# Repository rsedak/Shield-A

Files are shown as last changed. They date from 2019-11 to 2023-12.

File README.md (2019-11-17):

Introduction
============

Shield-A is Arduino Uno based shield for student education compatible with BASCOM-AVR(C) and Arduino IDE.
During programming please keep in mind next design rules:
- D0-D7 — LEDs can be used only if D12 is set to OUTPUT HIGH state
- LCD 1602 — can be used only if A3 is set to OUTPUT HIGH state
- RGB LED — are connected in matrix (D5-D7 - colors; D8-D11 - LEDs)
- D12 — enables D0-D7 LEDs
- D13 — reserved for buzzer
- A0 — reserved for potentiometer
- A1,A2 — reserved for switch in INPUT_PULLUP mode
- A3 — enables LCD 1602 back-light
- A4,A5 — reserved for I2C communication with on board pull-up resistors

Contributors
------------
- Petar Jurković — an initial idea for the educational shield with a list of features, QA test.
- Vladimir Mitrović — features, BASCOM-AVR expertise, schematic design
- Robert Sedak — features, Arduino expertise, schematic design, CAD design. 

Application
-----------
Robert Sedak made a video with examples programmed in Arduino IDE:

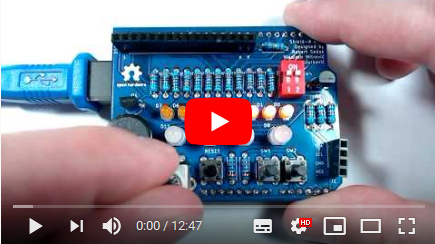
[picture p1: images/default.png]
Shield application (https://youtu.be/6tAJYVBwVqs "Shield-A examples")


You can download examples from [here](examples/). 
Examples which name ends with '_R' are solution with register maniputalion.

Bill Of Materials
-----------------
- 1 ea., PCB from [PCBway.com](https://www.pcbway.com/project/shareproject/Shield_A_for_Arduino_Uno.html)
- 9 ea., 1K ohm 1/4W 1% Resistor (R1-R8, R13)
- 2 ea., 100 ohm 1/4W 1% Resistor (R9, R10)
- 2 ea., 560 ohm 1/4W 1% Resistor (R11-R12)
- 4 ea., 10K ohm 1/4W 1% Resistor (R14, R15, R17, R18)
- 2 ea., 18.2 ohm 1/4W 1% Resistor (R16)
- 8 ea., LED 3mm (D0-D7)
- 4 ea., RGB LED 5mm common Katode (D8-D11)
- 1 ea., 14x7.5mm passive electronic piezoelectric buzzer SE
- 2 ea., MOSFET BS170
- 1 ea., 3386-P 10K potentiometer with knob
- 1 ea., RV09 10K potentiometer - long shaft
- 1 ea., 2.54mm pitch slide DIP switch 2-bit
- 1 ea., 6x6x4.3mm SPST Momentary push switch
- 2 ea., 6x6x10mm SPST Momentary push switch
- 1 ea., 1x16Pin 2.54mm Straight Pin Header - Black
- 1 ea., 1x10Pin 2.54mm Straight Pin Header - Black
- 2 ea., 1x8Pin 2.54mm Straight Pin Header - Black
- 1 ea., 1x6Pin 2.54mm Straight Pin Header - Black
- 1 ea., 1x4 pin 2.54mm Socket Connector
- 1 ea., 1x16 pin 2.54mm Socket Connector
- 1 ea., LCD 1602 HD44780 (pin 15 is anode, pin 16 is katode)

Design Files
------------
This project is designed using Open Source [KiCad](http://kicad-pcb.org/). Design files are located in the [design_files](design_files/) folder.  You can see the [schematic](images/shield-a_schematic.png).

Gerber files
------------
You can download gerber files from [here](gerber/shield_a_v1.1.zip).

Firmware
--------
This project can be programmed using the Open Source [Arduino](https://www.arduino.cc/) and [BASCOM-AVR(C)](https://www.mcselec.com/index.php?option=com_content&task=view&id=14&Itemid=103).
Arduino examples are located in [examples](examples/) folder.

Assembly Instructions
---------------------
TBD

License
-------
[Attribution-ShareAlike 4.0 International (CC BY-SA 4.0)](https://creativecommons.org/licenses/by-sa/4.0/)

You are free to:
- Share — copy and redistribute the material in any medium or format
- Adapt — remix, transform, and build upon the material

This license is acceptable for Free Cultural Works.
- The licensor cannot revoke these freedoms as long as you follow the license terms.

Under the following terms:
- Attribution — You must give appropriate credit, provide a link to the license, and indicate if changes were made. You may do so in any reasonable manner, but not in any way that suggests the licensor endorses you or your use.
- ShareAlike — If you remix, transform, or build upon the material, you must distribute your contributions under the same license as the original.

No additional restrictions — You may not apply legal terms or technological measures that legally restrict others from doing anything the license permits.

Reference Designs ARE PROVIDED "AS IS" AND "WITH ALL FAULTS". Authors DISCLAIMS ALL OTHER WARRANTIES, EXPRESS OR IMPLIED, REGARDING PRODUCTS, INCLUDING BUT NOT LIMITED TO, ANY IMPLIED WARRANTIES OF MERCHANTABILITY OR FITNESS FOR A PARTICULAR PURPOSE.
Authors may make changes to specifications and product descriptions at any time, without notice. The Customer must notrely on the absence or characteristics of any features or instructions marked "reserved" or "undefined." 
Authors reservesthese for future definition and shall have no responsibility whatsoever for conflicts or incompatibilities arising from future changes to them. The product information on the Web Site or Materials is subject to change without notice. Do not finalize a design with this info.

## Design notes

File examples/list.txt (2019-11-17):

Examples
001 D0 blinks
002 D0 and D1 blinks
003 D0-D7 turning on LEDs - from D0 to D7
004 D0-D7 turning on LEDs - from D0 to D7; turning off LEDs - from D7 to D0
005 D0-D7 running light - from from D0 to D7
006 D0-D7 running light - from D0 to D7 and from D7 to D0
007 D0-D7 turning on LEDs - from D7 to D0
008 D0-D7 turning on LEDs - from D7 to D0; turning off LEDs - from D0 to D7
009 D0-D7 running light - from D7 to D0
010 D0-D7 running light - from D7 to D0 and from D0 to D7
011 D0-D7 four LEDs shift from D7 to D0
012 D0-D7 four LEDs shift from D0 to D7
013 D0-D7 two even LEDs shift from D7 to D0
014 D0-D7 two even LEDs shift from D0 to D7
015 D0-D7 animation
016 RGB matrix - red
017 RGB matrix - red, blue, green - one RGB LED
018 RGB matrix - red, blue, green - four RGB LED
019 RGB matrix - white - one RGB
020 RGB matrix - multiplexing four RGB LED
021 RGB matrix - multiplexing four RGB LED
022 RGB matrix - multiplexing four RGB LED
023 RGB matrix - multiplexing four RGB LED
024 RGB matrix - multiplexing four RGB LED
025 Buzzer and SW1
026 Buzzer, SW1 and SW2 - different tone
027 D0-D7, SW1, SW2 - Turning On / Off D0
028 D0-D7, SW1, SW2 - while SW1 is pressed, light runs in direction from D0 to D7; while SW2 is pressed, light runs in direction from D7 to D0
029 D0-D7, SW1, SW2 - for SW1 pressed, light moves in direction from D0 to D7 for one LED; for SW2 pressed, light moves in direction from D7 to D0 for one LED
030 D0-D7, SW1, SW2 - for SW1 pressed, light moves in direction from D0 to D7 for one LED; for SW2 pressed, light moves in direction from D7 to D0 for one LED - debounce
031 D0-D7, SW1, SW2 - when SW1 is short pressed, light moves in direction from D0 to D7 for one LED; when SW1 is pressed for 3 seconds, light moves in direction from D0 to D7 for one LED continuously; when SW2 is short pressed, light moves in direction from D7 to D0 for one LED; when SW2 is pressed for 3 seconds, light moves in direction from D7 to D0 for one LED continuously  - debounce
032 D0-D7 and RV1 - running light - from D0 to D7 depending on potentiometer shaft position
033 D0-D7 and RV1 - running light - from D7 to D0 depending on potentiometer shaft position
034 D0-D7 and RV1 - turning on LEDs - from D0 to D7 depending on potentiometer shaft position
035 D0-D7 and RV1 - turning on LEDs - from D7 to D0 depending on potentiometer shaft position
036 D0-D7 and RV1 - turning on LEDs from the centre to the edge depending on potentiometer shaft position
037 D0-D7 and RV1 - turning on LEDs from the edge to the centre depending on potentiometer shaft position
038 RV1 and buzzer - Making a noise
039 RV1, LCD - Show analogue input value
040 RV1, LCD (I2C) - Show analogue input value

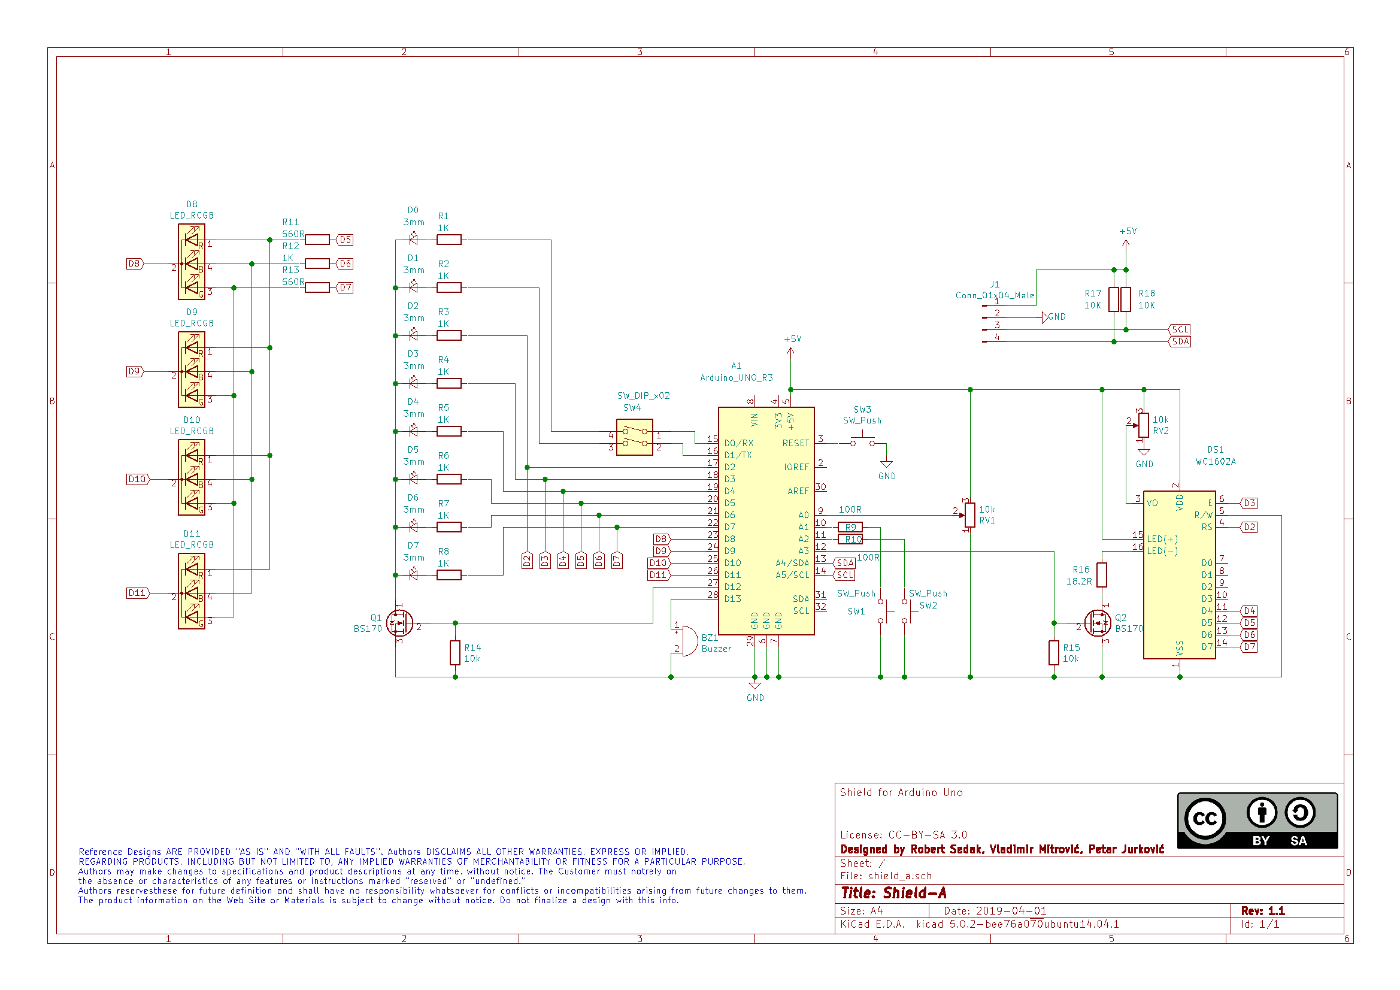
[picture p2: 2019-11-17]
images/shield-a_schematic.png

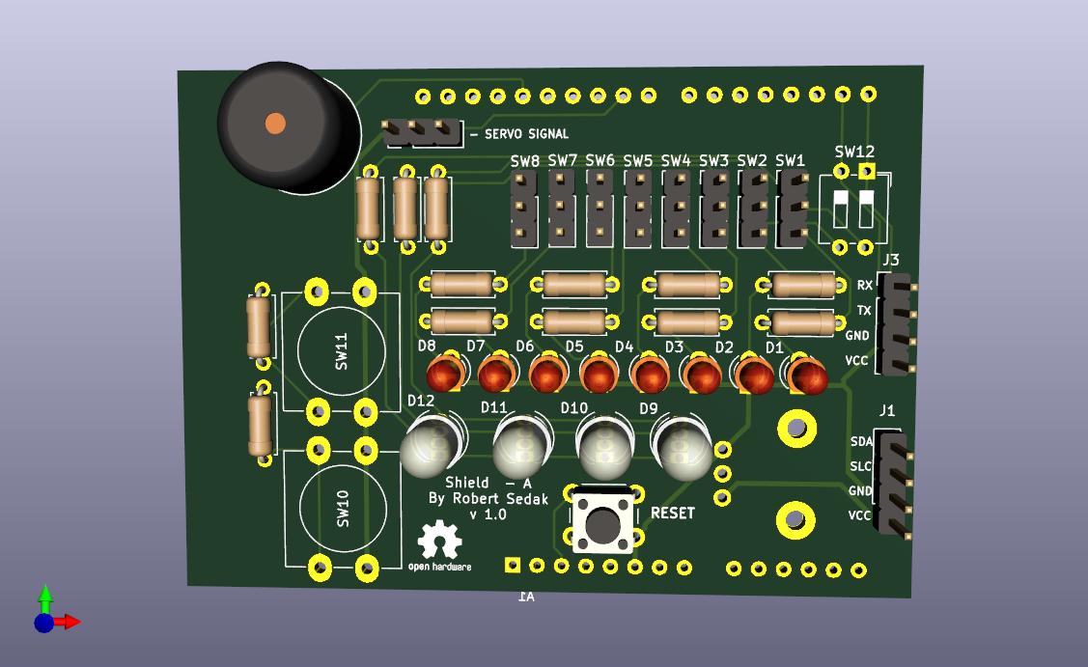
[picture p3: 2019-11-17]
images/shield-a.jpg

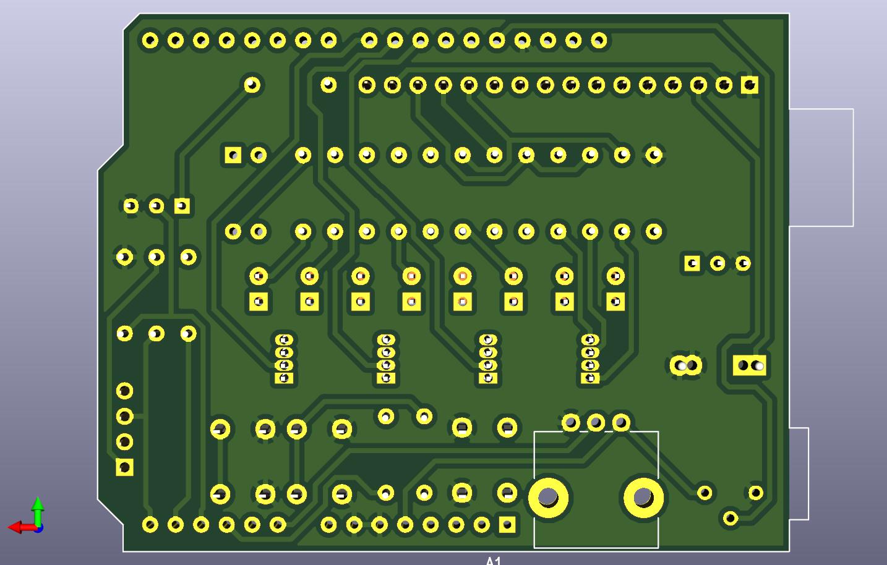
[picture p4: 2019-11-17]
images/shield-a_b.jpg

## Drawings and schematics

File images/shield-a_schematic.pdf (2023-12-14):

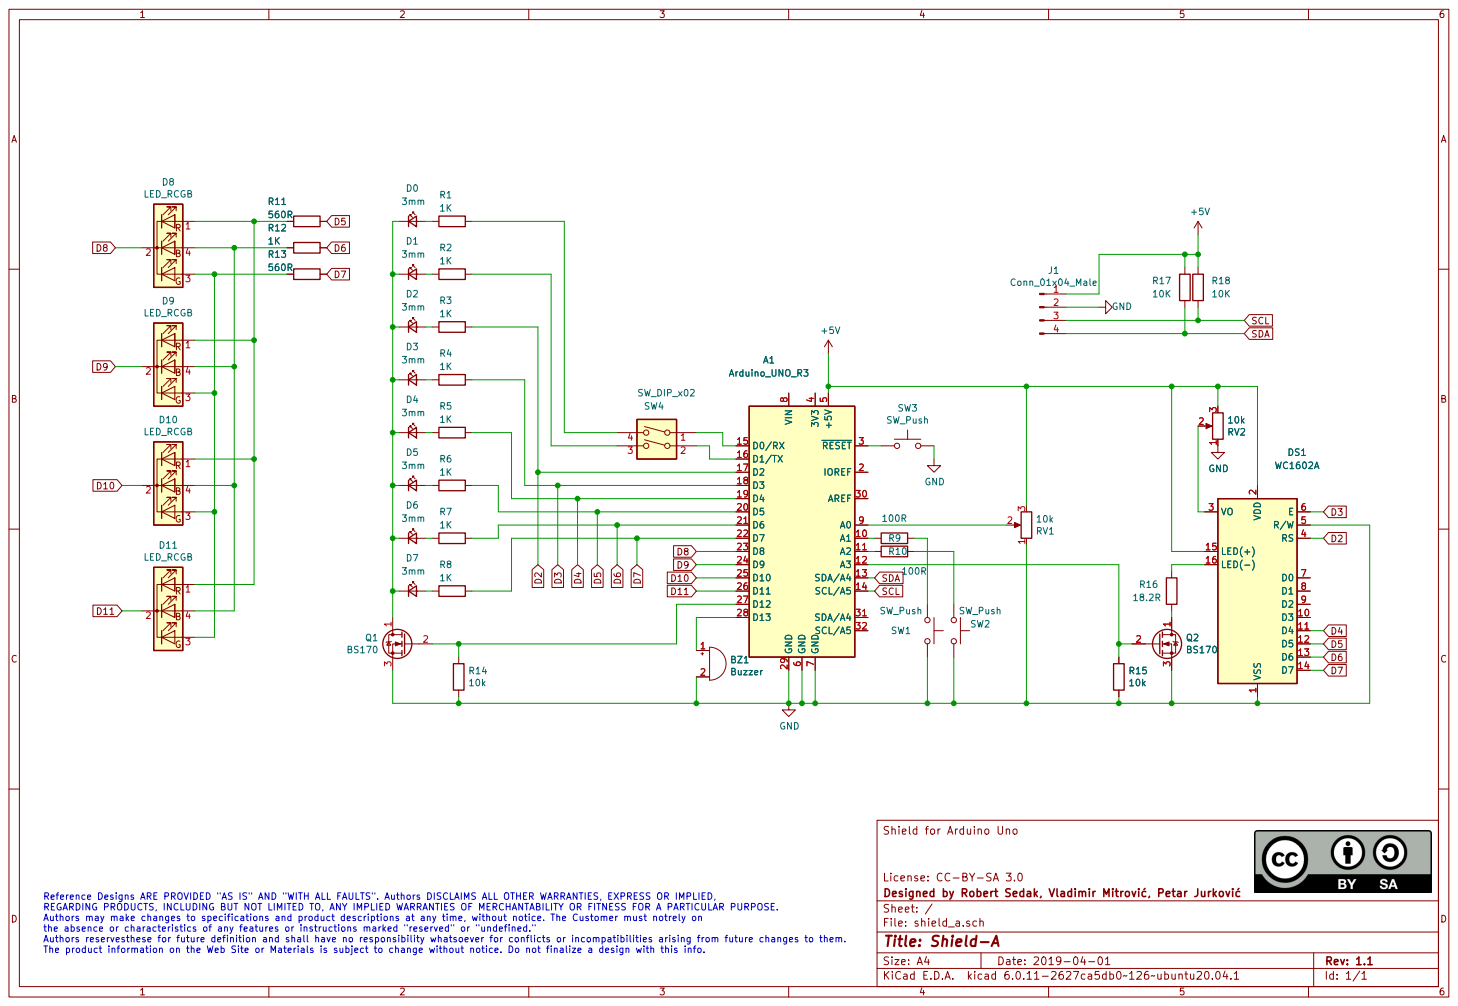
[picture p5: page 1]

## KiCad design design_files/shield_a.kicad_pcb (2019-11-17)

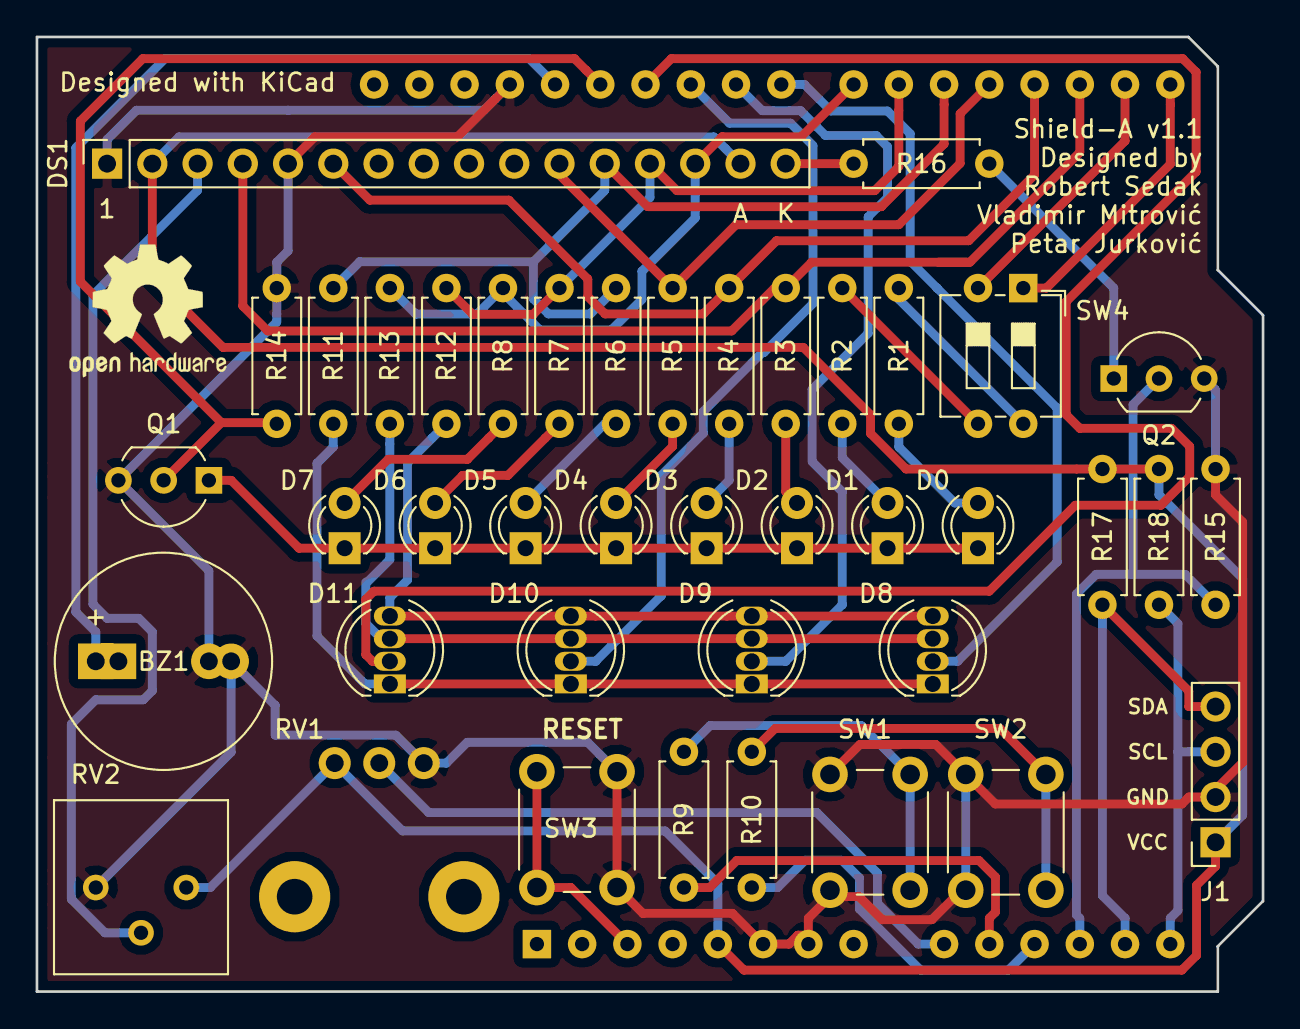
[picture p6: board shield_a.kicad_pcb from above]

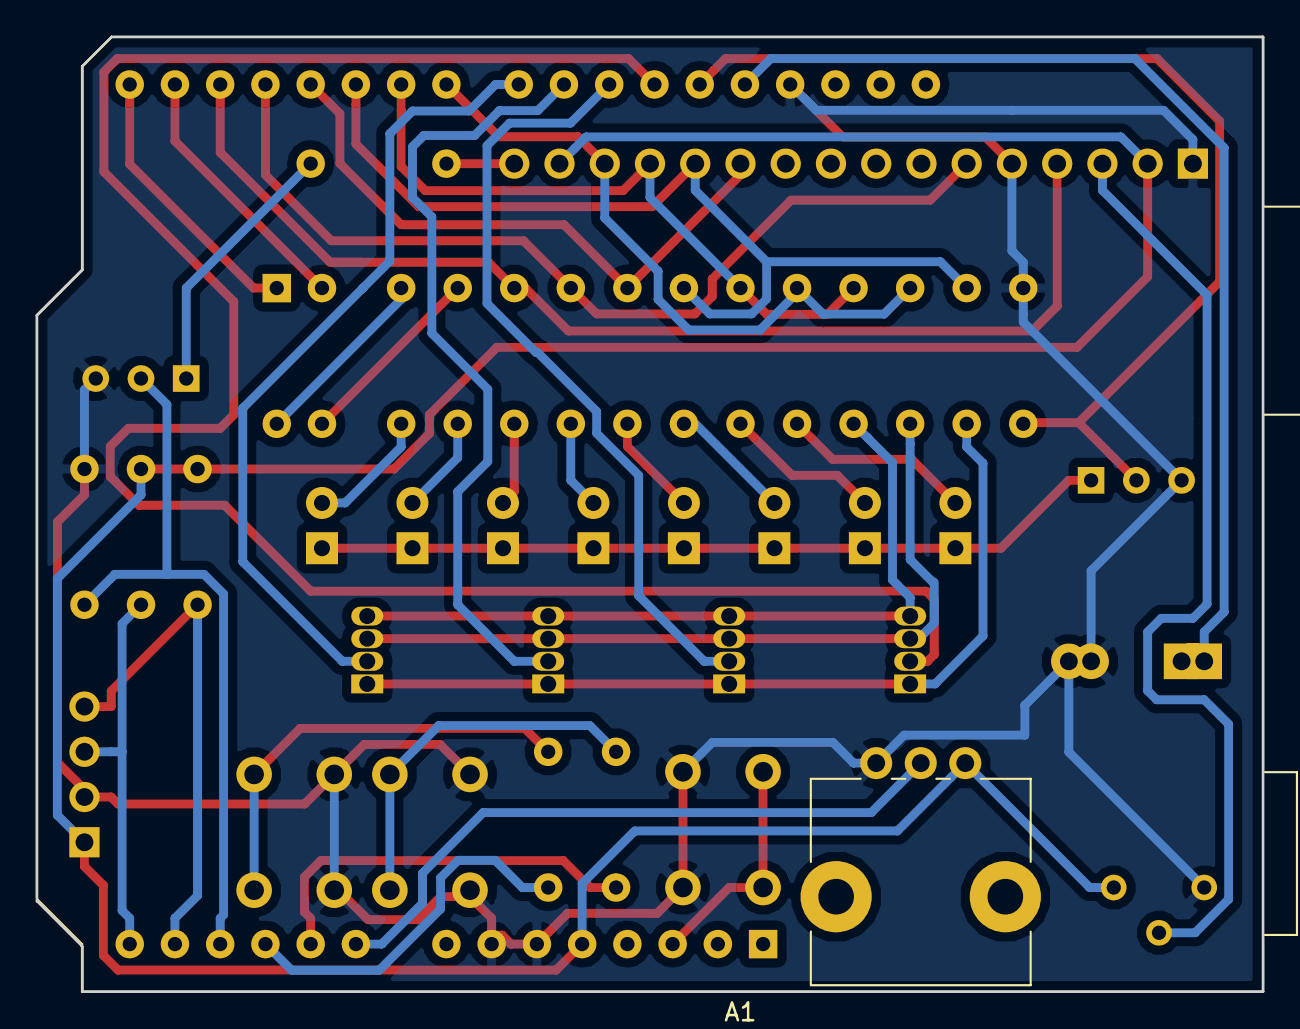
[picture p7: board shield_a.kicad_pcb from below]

Board: 2 copper layers, 68.8 x 53.6 mm, 42 parts (2 on the bottom side), 42 nets.

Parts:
A1: Arduino_UNO_R3
BZ1: Buzzer; Buzzer_12x9.5RM7.6_5
D0, D1, D2, D3, D4, D5, D6, D7: 3mm; LED_D3.0mm
D8, D9, D10, D11: LED_RCBG; LED_D5.0mm-4_RGB
DS1: WC1602A; PinSocket_1x16_P2.54mm_Vertical
J1: Conn_01x04_Male; PinSocket_1x04_P2.54mm_Vertical
Q1, Q2: BS170; TO-92_Inline_Wide
R1, R2, R3, R4, R5, R6, R7, R8: 1.5K; R_Axial_DIN0207_L6.3mm_D2.5mm_P7.62mm_Horizontal
R9, R10: 100R; R_Axial_DIN0207_L6.3mm_D2.5mm_P7.62mm_Horizontal
R11, R12, R13: 470; R_Axial_DIN0207_L6.3mm_D2.5mm_P7.62mm_Horizontal
R14, R15: 10k; R_Axial_DIN0207_L6.3mm_D2.5mm_P7.62mm_Horizontal
R16: 18R; R_Axial_DIN0207_L6.3mm_D2.5mm_P7.62mm_Horizontal
R17, R18: 10K; R_Axial_DIN0207_L6.3mm_D2.5mm_P7.62mm_Horizontal
RV1: 10k; Potentiometer_Alps_RK09L_Single_Vertical
RV2: 10k; Potentiometer_Bourns_3386P_Vertical
SW1, SW2, SW3: SW_Push; SW_PUSH_6mm
SW4: SW_DIP_x02; SW_DIP_SPSTx02_Slide_6.7x6.64mm_W7.62mm_P2.54mm_LowProfile

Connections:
+5V: A1.5, DS1.2, DS1.15, J1.1, R17.2, R18.2, RV1.3, RV2.3
A1: R9.1, SW1.1
A2: R10.1, SW2.1
D2: A1.17, DS1.4, R3.1
D3: A1.18, DS1.6, R4.1
D4: A1.19, DS1.11, R5.1
D5: A1.20, DS1.12, R6.1, R11.1
D6: A1.21, DS1.13, R7.1, R12.1
D7: A1.22, DS1.14, R8.1, R13.1
D8: A1.23, D8.2
D9: A1.24, D9.2
D10: A1.25, D10.2
D11: A1.26, D11.2
GND: A1.6, A1.7, A1.29, BZ1.2, DS1.1, DS1.5, J1.2, Q1.3, Q2.3, R14.2, R15.2, RV1.1, RV2.1, SW1.2, SW2.2, SW3.2
unnamed: A1.3, SW3.1
unnamed: A1.9, RV1.2
unnamed: A1.10, R9.2
unnamed: A1.11, R10.2
unnamed: A1.12, Q2.2, R15.1
unnamed: A1.15, SW4.1
unnamed: A1.16, SW4.2
unnamed: A1.27, Q1.2, R14.1
unnamed: A1.28, BZ1.1
unnamed: D0.1, D1.1, D2.1, D3.1, D4.1, D5.1, D6.1, D7.1, Q1.1
unnamed: D0.2, R1.2
unnamed: D1.2, R2.2
unnamed: D2.2, R3.2
unnamed: D3.2, R4.2
unnamed: D4.2, R5.2
unnamed: D5.2, R6.2
unnamed: D6.2, R7.2
unnamed: D7.2, R8.2
unnamed: D8.1, D9.1, D10.1, D11.1, R11.2
unnamed: D8.3, D9.3, D10.3, D11.3, R13.2
unnamed: D8.4, D9.4, D10.4, D11.4, R12.2
unnamed: DS1.3, RV2.2
unnamed: DS1.16, R16.1
unnamed: Q2.1, R16.2
unnamed: R1.1, SW4.4
unnamed: R2.1, SW4.3
SCL: A1.14, J1.3, R18.1
SDA: A1.13, J1.4, R17.1

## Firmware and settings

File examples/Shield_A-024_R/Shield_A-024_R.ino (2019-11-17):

/* RGB matrix 
 * multiplexing four RGB LED
 * with register manipulation  
 * 
 * Arduino Digital Pin | Register Pin Mark
 * ----------------------------------------
 *                   0 | PD0 
 *                   1 | PD1 
 *                   2 | PD2 
 *                   3 | PD3
 *                   4 | PD4
 *                   5 | PD5
 *                   6 | PD6
 *                   7 | PD7
 *                   8 | PB0
 *                   9 | PB1
 *                  10 | PB2
 *                  11 | PB3
 *                  12 | PB4
 *                  13 | PB5 
 * 
 * Created 2019 by Robert Sedak
 * 
 * This example code is in the public domain.
 *  
 *  THE SOFTWARE IS PROVIDED "AS IS", WITHOUT WARRANTY OF ANY KIND, 
 *  EXPRESS OR IMPLIED, INCLUDING BUT NOT LIMITED TO THE WARRANTIES 
 *  OF MERCHANTABILITY, FITNESS FOR A PARTICULAR PURPOSE AND 
 *  NONINFRINGEMENT. IN NO EVENT SHALL THE AUTHOR(S) OR 
 *  CONTRIBUTOR(S) BE LIABLE FOR ANY CLAIM, DAMAGES OR OTHER 
 *  LIABILITY, WHETHER IN AN ACTION OF CONTRACT, TORT OR OTHERWISE, 
 *  ARISING FROM, OUT OF OR IN CONNECTION WITH THE SOFTWARE OR 
 *  THE USE OR OTHER DEALINGS IN THE SOFTWARE.
 */

byte D8;
byte D9;
byte D10;
byte D11;
int RGBDelay = 2;  // delay 2ms
unsigned long lastTime = 0;
int randomNumber = 0;

void setup() {

  // Set D5-D7 as output pins 
  DDRD |= ((1 << PD5) | (1 << PD6) | (1 << PD7));

  // Set D8-D11 as output pins 
  DDRB |= ((1 << PB0) | (1 << PB1) | (1 << PB2) | (1 << PB3));
  
  // Turn OFF RED, Blue and Green LED
  PORTD &= ~((1 << PD5) | (1 << PD6) | (1 << PD7));

  // Turn OFF D8, D9, D10 and D11 RGB LED - pins are in HIGH state
  PORTB |= ((1 << PB0) | (1 << PB1) | (1 << PB2) | (1 << PB3));

  // Seed ranodom generator
  randomSeed(analogRead(A6));
} // end of setup function

void loop() {

  // define new random colors for RGB LEDs every second
  // no LED can not have same color
  if ((millis() - lastTime) > 1000) {
    D8 = random(1,8);
    randomNumber = random(1,8);
    while ( D8 == randomNumber ) {
      randomNumber = random(1,8);
    }
    D9 = randomNumber;

    while (    D8 == randomNumber 
            || D9 == randomNumber ) {
      randomNumber = random(1,8);
    }    
    D10 = randomNumber;
    while (    D8 == randomNumber 
            || D9 == randomNumber 
            || D10 == randomNumber) {
      randomNumber = random(1,8);
    }
    D11 = randomNumber;
    lastTime = millis();
  }
  
  PORTB &= ~(1 << PB0);   // Turn ON RGB LED D8
  PORTB |= (1 << PB3);    // Turn OFF RGB LED D11
  PORTD = (D8 << 5);      // Set color defined in variable D8
  
  delay(RGBDelay);

  PORTB |= (1 << PB0);    // Turn OFF RGB LED D8
  PORTB &= ~(1 << PB1);   // Turn ON RGB LED D9
  PORTD = (D9 << 5);      // Set color defined in variable D9
  
  delay(RGBDelay);

  PORTB |= (1 << PB1);   // Turn OFF RGB LED D9
  PORTB &= ~(1 << PB2);  // Turn ON RGB LED D10
  PORTD = (D10 << 5);    // Set color defined in variable D10
  
  delay(RGBDelay);

  PORTB |= (1 << PB2);   // Turn OFF RGB LED D10
  PORTB &= ~(1 << PB3);  // Turn ON RGB LED D11 
  PORTD = (D11 << 5);    // Set color defined in variable D11
  
  delay(RGBDelay);
} // end of loop function

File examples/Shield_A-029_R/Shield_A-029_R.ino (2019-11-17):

/* D0-D7, SW1, SW2
 *  for SW1 pressed, light moves in direction from D0 to D7 for one LED
 *  for SW2 pressed, light moves in direction from D7 to D0 for one LED
 *  with register manipulation  
 *  
 * Arduino Digital Pin | Register Pin Mark
 * ----------------------------------------
 *                   0 | PD0 
 *                   1 | PD1 
 *                   2 | PD2 
 *                   3 | PD3
 *                   4 | PD4
 *                   5 | PD5
 *                   6 | PD6
 *                   7 | PD7
 *                   8 | PB0
 *                   9 | PB1
 *                  10 | PB2
 *                  11 | PB3
 *                  12 | PB4
 *                  13 | PB5 
 *                  A0 | PC0
 *                  A1 | PC1
 *                  A2 | PC2
 *                  A3 | PC3
 *                  A4 | PC4
 *                  A5 | PC5
 *                  A6 | PC6
 *  
 *  Created 2019 by Robert Sedak
 *  
 *  This example code is in the public domain.
 *  
 *  THE SOFTWARE IS PROVIDED "AS IS", WITHOUT WARRANTY OF ANY KIND, 
 *  EXPRESS OR IMPLIED, INCLUDING BUT NOT LIMITED TO THE WARRANTIES 
 *  OF MERCHANTABILITY, FITNESS FOR A PARTICULAR PURPOSE AND 
 *  NONINFRINGEMENT. IN NO EVENT SHALL THE AUTHOR(S) OR 
 *  CONTRIBUTOR(S) BE LIABLE FOR ANY CLAIM, DAMAGES OR OTHER 
 *  LIABILITY, WHETHER IN AN ACTION OF CONTRACT, TORT OR OTHERWISE, 
 *  ARISING FROM, OUT OF OR IN CONNECTION WITH THE SOFTWARE OR 
 *  THE USE OR OTHER DEALINGS IN THE SOFTWARE.
 */

void setup() {
  // initialize digital pins 
  // 0, 1, 2, 3, 4, 5, 6 and 7 as an ouput
  DDRD  = B11111111;
  // initialize digital pin 12 as an output.
  DDRB |= (1 << PB4);  

  // turn the MOSFET switch Q1 on
  PORTB |= (1 << PB4);  

  // turn the D9 LED on
  PORTD |= (1 << PD0);
  
  // Set SW1 as input pin
  DDRC &= ~(1 << PC1);
  // Set pullup resistor for SW1
  PORTC |= (1 << PC1);

  // Set SW2 as input pin
  DDRC &= ~(1 << PC2);
  // Set pullup resistor for SW2
  PORTC |= (1 << PC2);

  // let it stabilize
  delay(20);
} // end of setup function

void loop() {

  // read the state of the SW1 push button value
  // and check if the push button is pressed.
  if (((PINC & (1 << PC1)) >> PC1) == 0) {
        
    // Rotate D register to left for one step 
    PORTD  = ( PORTD << 1 ) | ( PORTD >> 7);
    
    // read the state of the SW1 push button value
    // and check if the push button is pressed.
    // while SW1 push button is pressed, do notihing
    while (((PINC & (1 << PC1)) >> PC1) == 0){
    }
  }

  // read the state of the SW2 push button value
  // and check if the push button is pressed. 
  if (((PINC & (1 << PC2)) >> PC2) == 0){
    
    // Rotate D register to right for one step  
    PORTD  = ( PORTD >> 1 ) | ( PORTD << 7);
    
    // read the state of the SW2 push button value
    // and check if the push button is pressed.    
    // while SW2 push button is pressed, do notihing
    while (((PINC & (1 << PC2)) >> PC2) == 0){
    }
  }
  
} // end of loop function

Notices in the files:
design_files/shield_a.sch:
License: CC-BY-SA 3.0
